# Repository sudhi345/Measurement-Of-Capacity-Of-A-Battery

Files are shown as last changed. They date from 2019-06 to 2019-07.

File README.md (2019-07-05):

# mAhTime

### Objective :

To calculate the battery life for a device using small batteries and intern use the data to calculate for any bigger battery.

###  Why do we need this?

The capacity of a battery is measured in Ah (ampere-hours, for large batteries) or mAh (milliampere-hours, for small batteries). 
This is usually mentioned on the battery or in the datasheets provided by the manufacturer.
But the capacity changes depending on the age of the battery, operating conditions, slightly different chemical composition, etc. 
So it affects the final result if use the capacity value provided by the manufacturer. 
*[learn more.](https://batteryuniversity.com/learn/article/battery_definitions)*
 
To get the actual capacity (close-enough-value), measuring the same is the method. 
Different methods using which one can measure the capacity, for example, Coulomb counting, Voltage monitoring, etc.
*(Learn more [here](https://www.quora.com/How-can-we-measure-a-batterys-real-capacity-in-Mah-or-ah-accurately) or 
[here](https://batteryuniversity.com/learn/article/how_to_measure_capacity)).*

Here we use the second method; monitoring the terminal voltage when a known load (resistive) is connected. 

### Method:

The batteries are charged and connected to a custom-designed shield for the esp8266 microcontroller and a load is selected using a button.
The microcontroller logs the terminal voltage read from its pin to a remote server until the lower cut off voltage for the batteries is reached.
The loads are automatically disconnected using logic level p-MOS switches. 
A python script displays the discharge curve and the area under the 
curve (area under the V*I v/s t curve is power rating and area under the I v/s t curve is the mAh / Ah of the batteries).<br>
Once again the batteries are charged but this time Device Under Test (DUT) is selected instead of a load (using the same microcontroller). 
The time taken for the DUT to discharge the batteries is found. This can then be used to calculate the life of any battery using ratios 
( Eg.: If for X (mAh) it is Y (no. of days) then for Z (mAh)? = YZ/X ).

### Hardware & Firmware:

A microcontroller unit (ESP8266-12E on LOLin board) has an inbuilt ADC (Analog to Digital Converter) with a precision of (1/1024)th of a volt.
But the input voltage range is only 0 (0) - 1V (1024). To use this in 0 - 3V range a resistor voltage divider is implemented 
using precision resistors and an n- MOS switch to enable this voltage divider.
The voltage divider is not the one which is present on the LOLin board. Those are not precision resistors, 
hence the readings may not be accurate.
The n-MOS switch is required as the voltage divider acts as another resistive load parallel to the selected load.
An OLED display is used to display the selected load, time, etc.

The hardware limits the maximum battery voltage to 3.6V as the battery voltage appears at pin A0 when voltage divider is disabled and the absolute maximum voltage given is 3.6V for esp8266. The time taken for measurement is determined by the capacity of the battery and the chosen load.

The circuit connections and the designed PCB can be found in the directory PCB_KICAD.
The details about the charger and the battery can be found in the 'Charger_hacked' directory. <br>
Arduino IDE is used to program the microcontroller. The required header files and libraries are in the 'upload_voltage' directory.

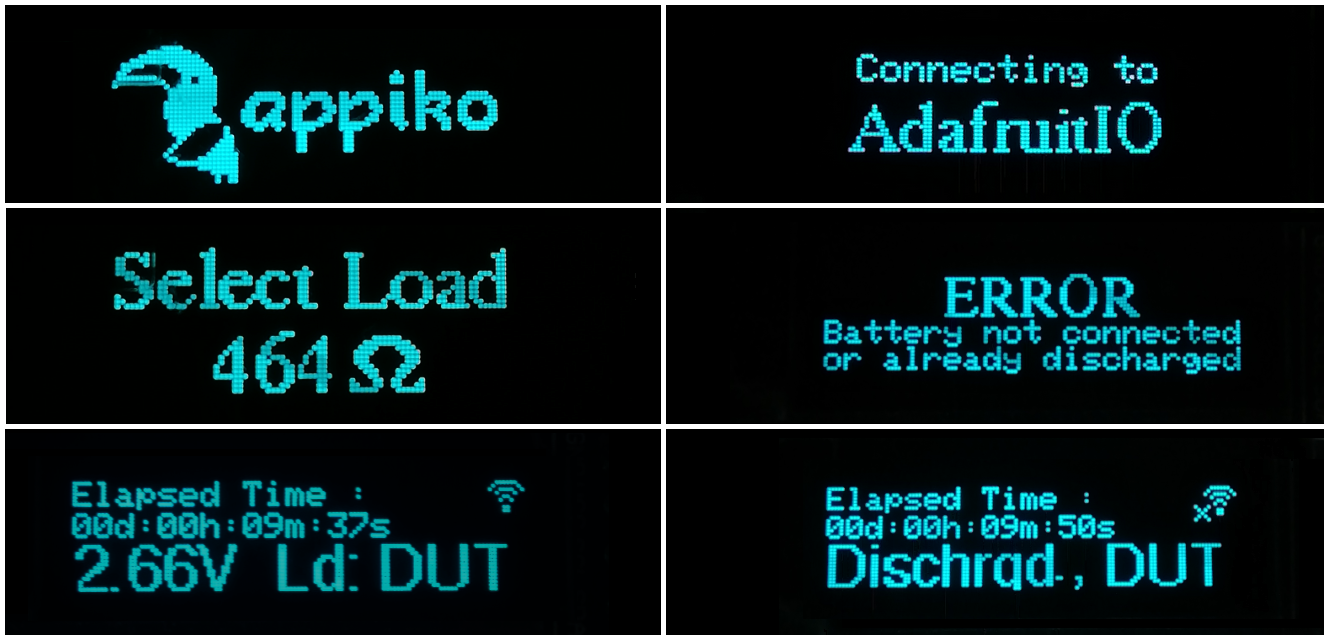
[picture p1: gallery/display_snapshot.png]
Snapshots of the display


### Result:

Here are pictures of graph and the PCB.
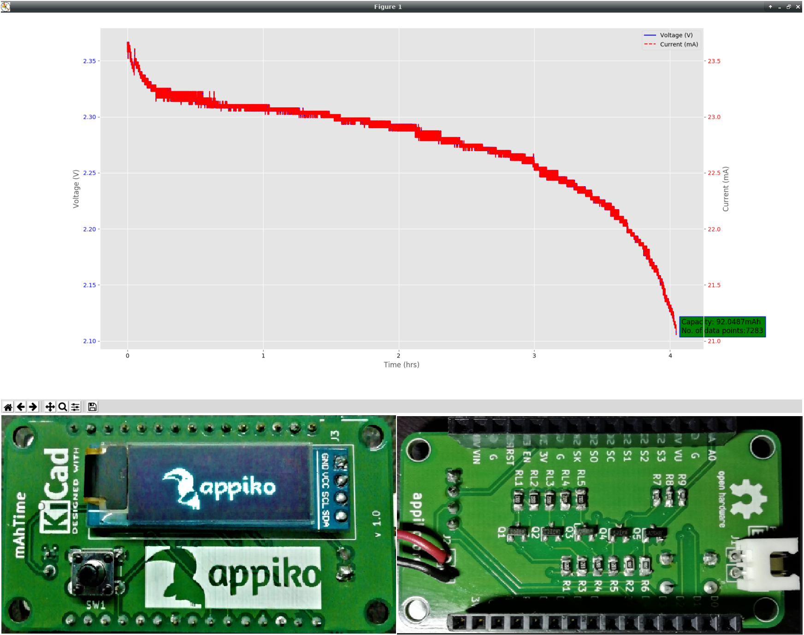
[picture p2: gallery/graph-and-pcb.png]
Graph and the soldered PCB


### Conclusion:

This project is helpful even if the DUT draws a few micro-amperes of current during sleep and few milli-amperes during high activity.
Hence the calculation of battery life is simplified with this.

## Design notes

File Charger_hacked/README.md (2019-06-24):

## Which battery and charger?

*Tuscan Gold* (model: TG-003) NiCd, NiMH battery charger to charge the *GP Battery* (17AAAH, 1.2V, C = 170mAh, NiMH,*1/3rd AAA*).

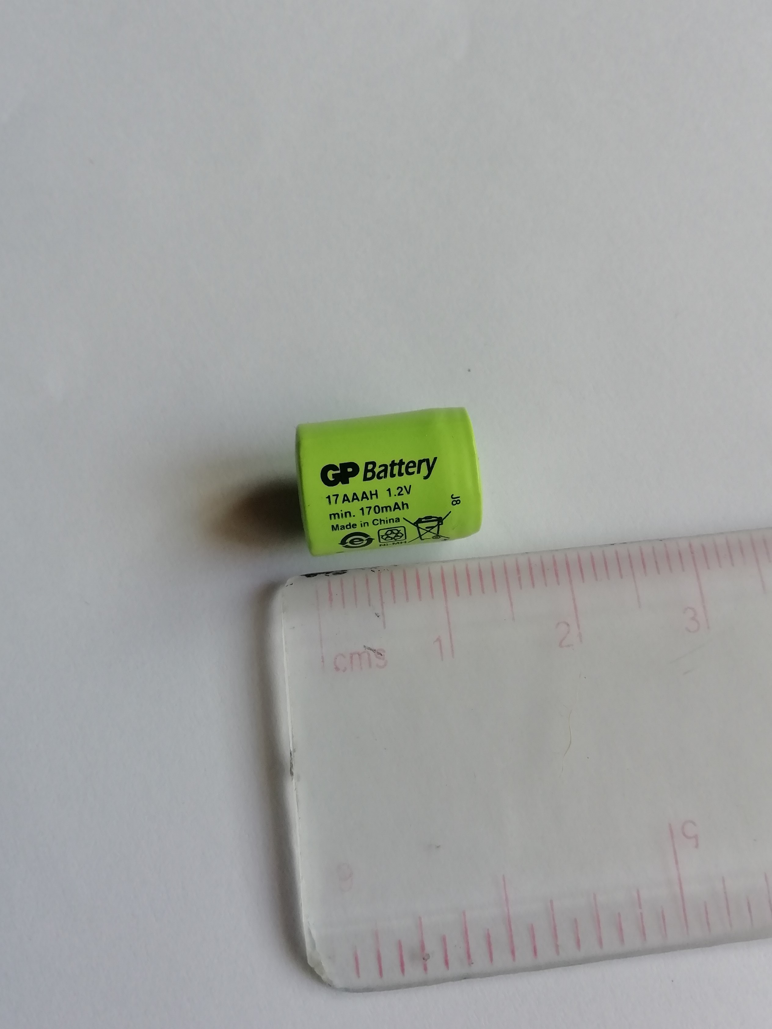
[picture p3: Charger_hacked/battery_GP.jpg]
1/3rd AAA battery


## Why the charger needs modifications?

Rated current capacity of the charger for the AAA size batteries (2S) is 100mA which is NOT the recommended amount of current for the 
mentioned tiny batteries. For the NiMH battery it is recommemnded to charge at 0.1C or below (usually 0.05C) but very low current through 
the batteries will result in a long charge duration.  Another problem with these tiny batteries is that they can not be installed in the given 
slot as that is for full sized AAA batteries.

## What are the modifications?

1. The over current problem was solved by adding a 147ohm resistor is series with the charger terminals and achieved a current flow of around 
12mA (~0.07C). Thses batteries (NiMH/NiCd) don't have floating terminal potential like Li-Ion batteries. So the change in voltage due to the 
added resistor across the terminals doesn't matter actually.
2. A pair of Molex connector was added to the charger with the wires connecting the terminals (One connector for 2S configuration. Resistor and
connections are invisible).

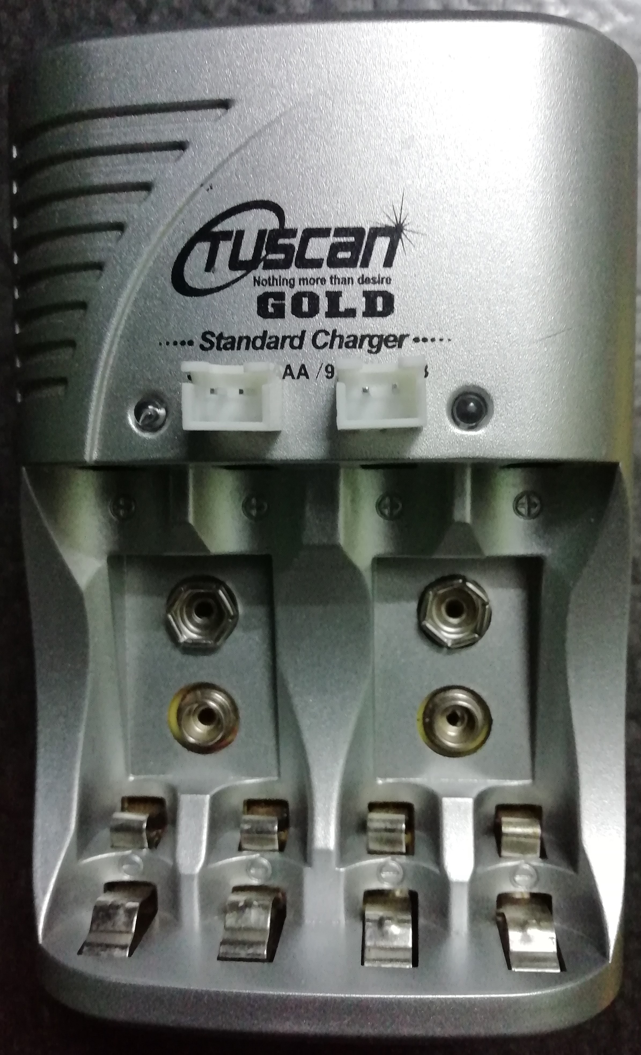
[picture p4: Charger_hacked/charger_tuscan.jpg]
Hacked charger


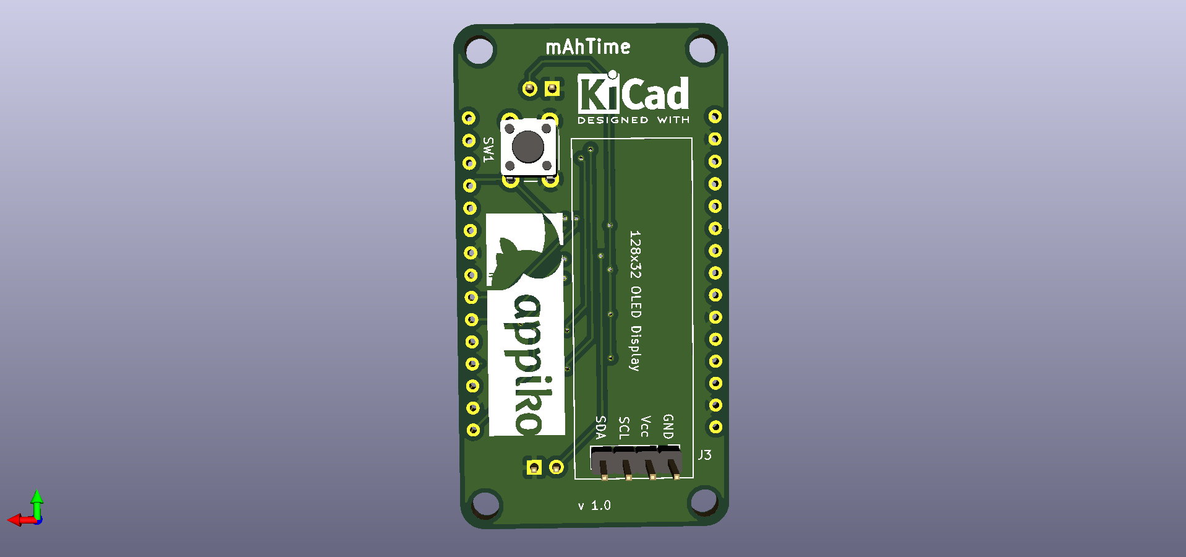
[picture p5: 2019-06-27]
PCB_KiCAD/images/pcb_3D_view_back.png

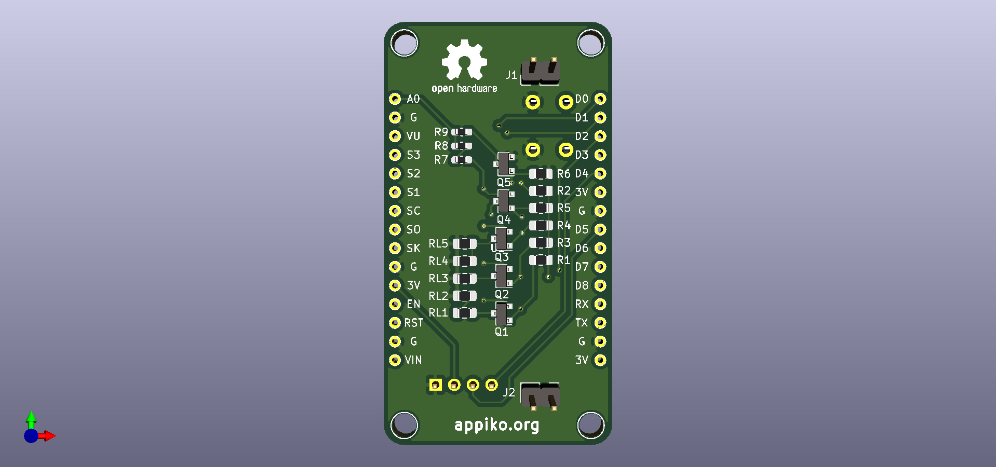
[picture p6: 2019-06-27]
PCB_KiCAD/images/pcb_3D_view.png

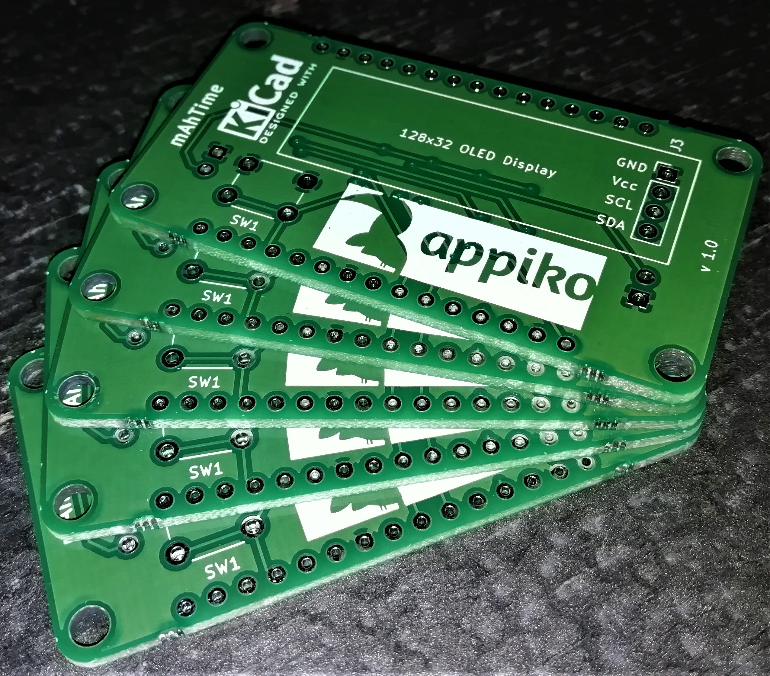
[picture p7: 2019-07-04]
gallery/pcb_stacked.jpg

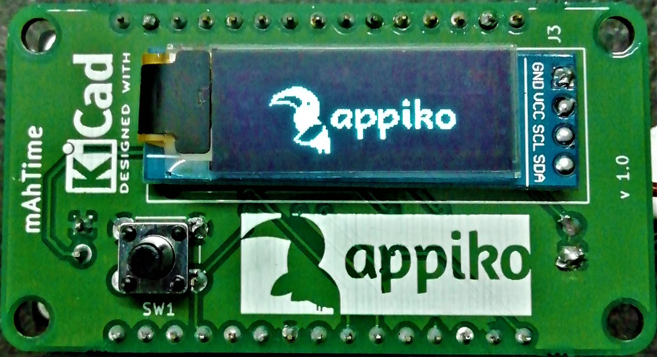
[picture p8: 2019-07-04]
gallery/pcb_powered.jpg

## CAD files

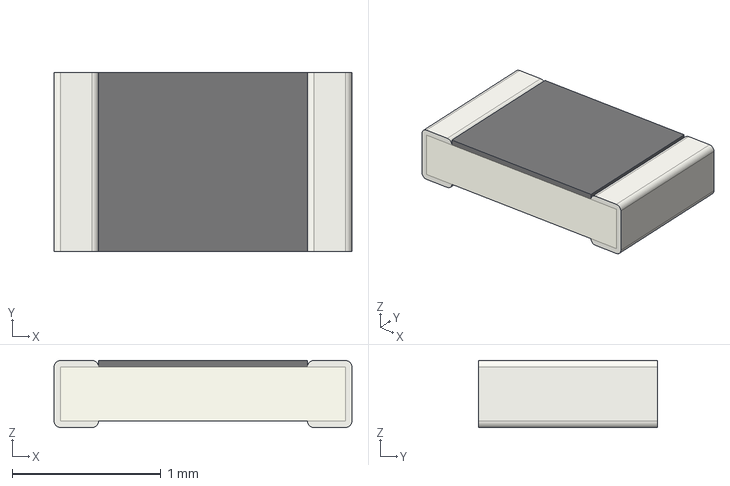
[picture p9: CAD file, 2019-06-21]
PCB_KiCAD/3D_models/R_0805_2012Metric.step
2.00 x 1.20 x 0.45 mm

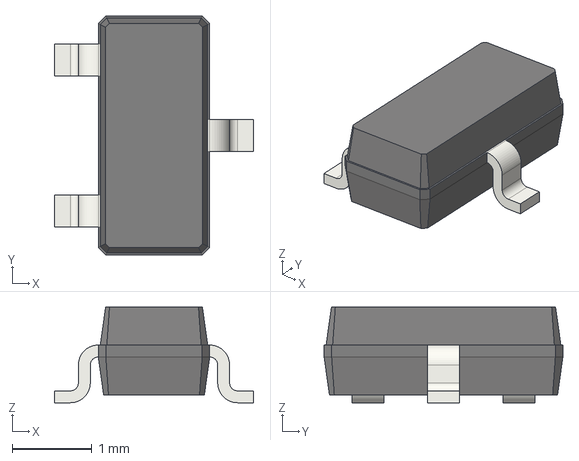
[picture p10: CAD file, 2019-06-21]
PCB_KiCAD/3D_models/SOT-23.step
2.50 x 3.00 x 1.20 mm

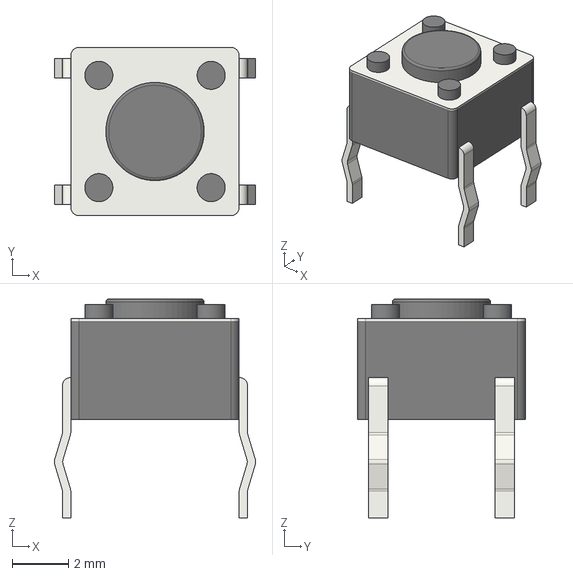
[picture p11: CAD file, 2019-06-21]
PCB_KiCAD/3D_models/SW_PUSH_6mm.step
7.17 x 6.00 x 7.80 mm

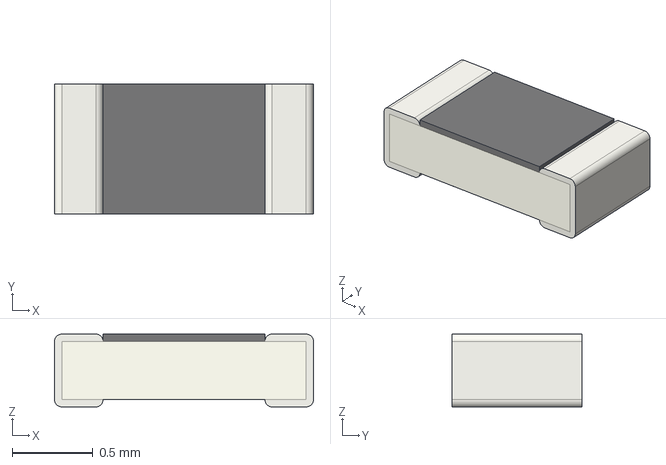
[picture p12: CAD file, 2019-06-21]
PCB_KiCAD/3D_models/R_0603_1608Metric.step
1.60 x 0.8 x 0.45 mm

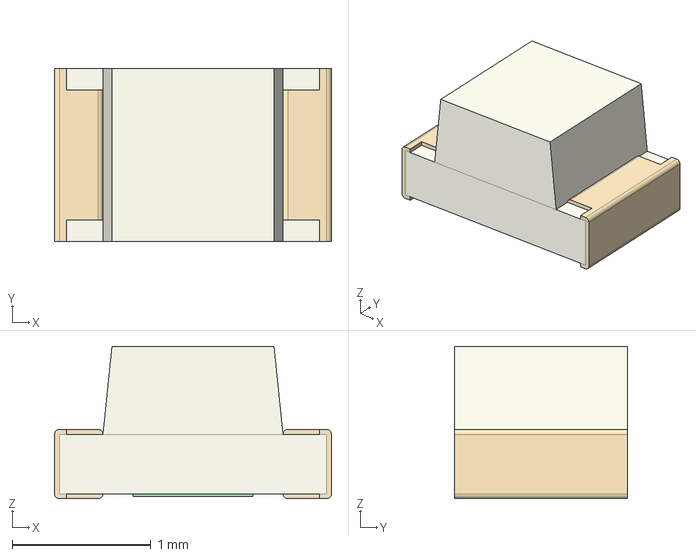
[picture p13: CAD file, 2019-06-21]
PCB_KiCAD/3D_models/LED_0805_2012Metric.step
2.00 x 1.25 x 1.10 mm

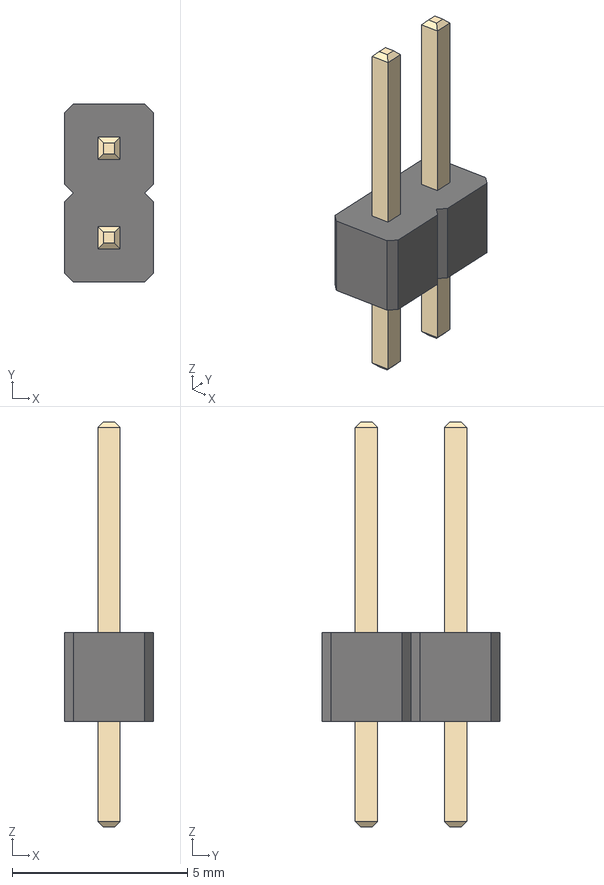
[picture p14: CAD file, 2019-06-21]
PCB_KiCAD/3D_models/PinHeader_1x02_P2.54mm_Vertical.step
2.54 x 5.08 x 11.5 mm

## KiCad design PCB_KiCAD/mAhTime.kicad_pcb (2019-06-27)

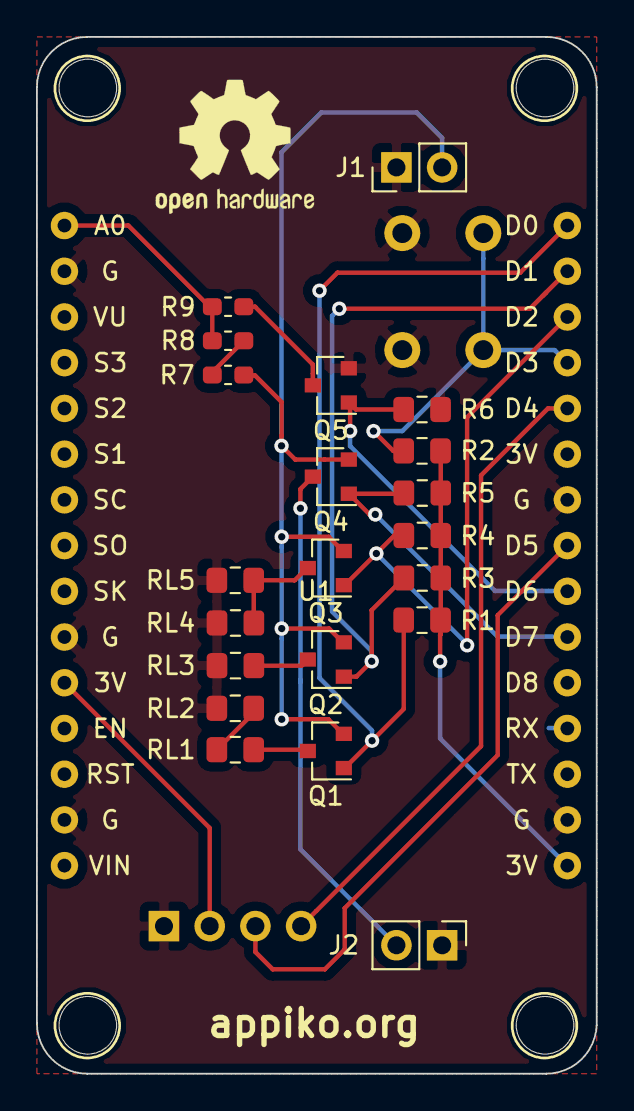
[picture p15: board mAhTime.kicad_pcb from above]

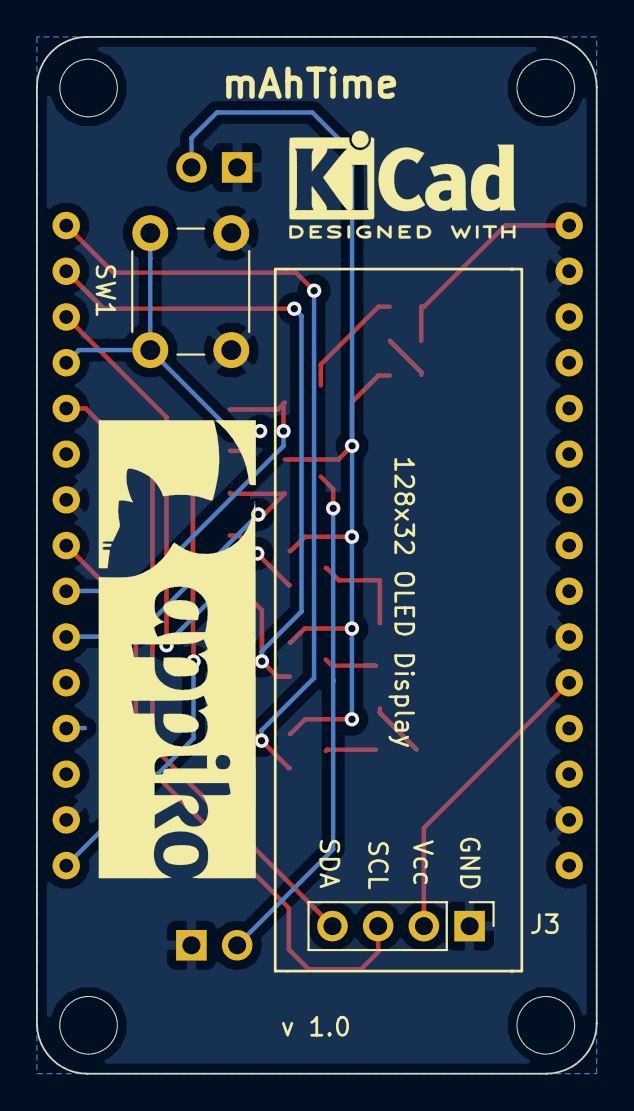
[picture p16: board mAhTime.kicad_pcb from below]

Board: 2 copper layers, 31.1 x 57.6 mm, 28 parts (2 on the bottom side), 19 nets.

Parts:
H1, H2, H3, H4: MountingHole; MountingHole_3.2mm_M3_ISO7380
J1: BATTERY; PinHeader_1x02_P2.54mm_Vertical
J2: DUT; PinHeader_1x02_P2.54mm_Vertical
J3: Conn_01x04; 128x32_OLED_Display
Q1, Q2, Q3, Q4: IRLML6401TRPBF; SOT-23
Q5: SI2302; SOT-23
R1, R3, R4, R5: 100k; R_0805_2012Metric_Pad1.15x1.40mm_HandSolder
R2: 1k; R_0805_2012Metric_Pad1.15x1.40mm_HandSolder
R6: 10k; R_0805_2012Metric_Pad1.15x1.40mm_HandSolder
R7, R8, R9: 30k; R_0603_1608Metric_Pad1.05x0.95mm_HandSolder
RL1, RL2, RL3, RL4, RL5: 232; R_0805_2012Metric_Pad1.15x1.40mm_HandSolder
SW1: SW_Push; SW_PUSH_6mm
U1: NodeMCU1.0(ESP-12E); NodeMCU-LoLinV3_without_border

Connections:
/Ctrl1: Q1.1, R1.2, U1.30
/Ctrl2: Q2.1, R3.2, U1.29
/Ctrl3: Q3.1, R4.2, U1.28
/Ctrl4: Q4.1, R5.2, U1.21
/En_VD: Q5.1, R6.2, U1.22
/SCL: J3.3, U1.23
/SDA: J3.4, U1.26
/SW: R2.2, SW1.1, U1.27
/Vbat: J1.2, Q1.2, Q2.2, Q3.2, Q4.2, R7.1
/Vcc: J3.2, R1.1, R2.1, R3.1, R4.1, R5.1, U1.11, U1.16, U1.25
/Vin: R8.2, R9.1, U1.1
/dut: J2.2, Q4.3
GND: J1.1, J2.1, J3.1, Q5.2, R6.1, RL2.2, RL3.2, RL4.2, RL5.2, SW1.2, U1.2, U1.10, U1.14, U1.17, U1.24
unnamed: Q1.3, RL1.1
unnamed: Q2.3, RL3.1
unnamed: Q3.3, RL4.1, RL5.1
unnamed: Q5.3, R9.2
unnamed: R7.2, R8.1
unnamed: RL1.2, RL2.1

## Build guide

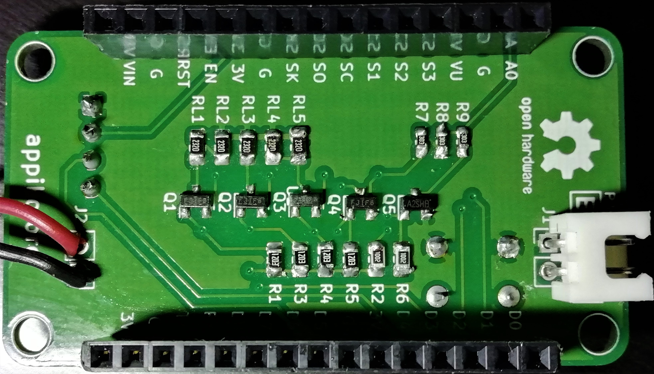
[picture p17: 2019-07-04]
gallery/pcb_soldered_2.jpg

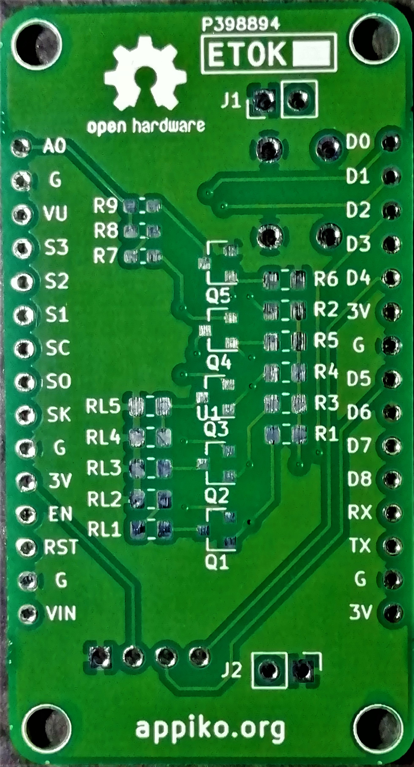
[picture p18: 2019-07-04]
gallery/pcb_unsoldered.jpg

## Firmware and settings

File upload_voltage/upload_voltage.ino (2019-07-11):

/********************************************************************************
BSD 3-Clause License

Copyright (c) 2019, Sudheendra Hegde
All rights reserved.

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
1. Redistributions of source code must retain the above copyright notice, this
   list of conditions and the following disclaimer.

2. Redistributions in binary form must reproduce the above copyright notice,
   this list of conditions and the following disclaimer in the documentation
   and/or other materials provided with the distribution.

3. Neither the name of the copyright holder nor the names of its
   contributors may be used to endorse or promote products derived from
   this software without specific prior written permission.

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
*****************************************************************************************/

#include "config.h"
#include "DischargeBattery.h"

float Vbat = 0, saved = 0;
float last = -1;

AdafruitIO_Feed *analog = io.feed("analog"); //Set up the feed. Replace "analog" in this line with the name of the feed that you created

void setup() {
  //set pinMode
  pinMode(LOAD1,OUTPUT);  //load resistance of 464ohm
  pinMode(LOAD2,OUTPUT);  //load resistance of 232ohm
  pinMode(LOAD3,OUTPUT);  //load resistance of 116ohm
  pinMode(DUT,OUTPUT);       //load is the Device Under Test (DUT)
  pinMode(SW,INPUT_PULLUP);         //push button (active high input)
  pinMode(EN_VOLTAGE_DIVIDER,OUTPUT);  //pin connected to gate of the mosfet which enables the voltage divider
  pinMode(Vin,INPUT);
  
  turnOffAllLoad();   //make sure all loads are off initially
  Wire.begin(SDA_PIN,SCL_PIN);
  display.begin(SSD1306_SWITCHCAPVCC, 0x3C);            // SSD1306_SWITCHCAPVCC = generate display voltage from 3.3V internally
  if(!display.begin(SSD1306_SWITCHCAPVCC, 0x3C)) {      // Address 0x3C for 128x32
    for(;;);                                            // SSD1306 allocation failed, Don't proceed, loop forever
  }
  display.clearDisplay();                       //clear the display buffer
  display.setRotation(2);                       //rotate 180 degerees
  display.drawBitmap(                           //draw bitmap image
    (display.width()  - logo_width ) / 2,       //align it at the center
    (display.height() - logo_height) / 2,
    logo, logo_width, logo_height, 1);
  display.display();                            //actually display the logo
  delay(2000);
  display.clearDisplay();        //clear the display buffer
  display.setTextSize(1);
  display.setTextColor(WHITE);
  display.setCursor(3,0);
  display.println("    Connecting to   ");
  display.setFont(&FreeSerif9pt7b);
  display.setCursor(0,24);
  display.println("     AdafruitIO    ");
  display.display(); // actually display all of the above
  
  io.connect();   // connect to io.adafruit.com
  
  // wait for a connection
  while(io.status() < AIO_CONNECTED) {
    delay(500);
  }
  display.clearDisplay();
  display.setCursor(25,18);
  display.println("Connected");
  display.display();
  delay(1000);
  queueInit();     //initialize queue
  checkBattery();   //verify whther connected battery has voltage > VLowerCutOff
  loadSelect();           //let the user select load / DUT
  display.setFont(&FreeSans9pt7b);  //change font to Sans
  StartTime = millis();     //save the starting time
}

void loop() {
  _time = millis();
  // io.run(); is required for all sketches. It should always be present at the top of your loop function. It keeps the client connected to
  // io.adafruit.com, and processes any incoming data.
  io.run();

  if( !ONCE_DISCHARGED )  
    Vbat = readVoltage();

  if( !(Vbat < VLowerCutOff) )
    enqueue(Vbat);    //enqueue the values 

  if(Vbat < VLowerCutOff)  {   //if the battery Vbat falls below the lower cut off
      ONCE_DISCHARGED = 1;         //clear the ONCE_DISCHARGED so that it does not oscillate when terminal Vbat rises slightly.
      turnOffAllLoad();    //turn OFF ALL loads when batteries got fully discharged.
      EndTime = millis();  //store end time
      DISP_ON = 1; //display that the batteries got discharged
      displayedAt = millis ();  //this is required when display is turned on using DISP_ON
      while(1){
        if (rear != front)    //queue is not empty
          if(!(io.status() < AIO_CONNECTED)) {     //connected 
            saved = dequeue();                             //read value from the queue
            analog->save(saved);                           // save the value to the feed
          } 
        checkForUpdate();
        yield();  
     }
  }
  
  while( (millis() - _time) < 2000){    //wait for 2 seconds
      checkForUpdate();
      if (rear != front)    //queue is not empty
        if(!(io.status() < AIO_CONNECTED)) {     //connected 
          saved = dequeue();                             //read value from the queue
          analog->save(saved);                           // save the value to the feed
        }
      yield();
  }
}

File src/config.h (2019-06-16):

/************************ Adafruit IO Config *******************************/

// visit io.adafruit.com if you need to create an account,
// or if you need your Adafruit IO key.
#define IO_USERNAME  "Username"
#define IO_KEY       "AIO"

/******************************* WIFI **************************************/

// the AdafruitIO_WiFi client will work with the following boards:
//   - HUZZAH ESP8266 Breakout -> https://www.adafruit.com/products/2471
//   - Feather HUZZAH ESP8266 -> https://www.adafruit.com/products/2821
//   - Feather HUZZAH ESP32 -> https://www.adafruit.com/product/3405
//   - Feather M0 WiFi -> https://www.adafruit.com/products/3010
//   - Feather WICED -> https://www.adafruit.com/products/3056
//   - Adafruit PyPortal -> https://www.adafruit.com/product/4116
//   - Adafruit Metro M4 Express AirLift Lite -> https://www.adafruit.com/product/4000
//   - Adafruit AirLift Breakout -> https://www.adafruit.com/product/4201

#define WIFI_SSID   "yourwifi"
#define WIFI_PASS   "wifipassword"

// uncomment the following line if you are using airlift
// #define USE_AIRLIFT

// uncomment the following line if you are using winc1500
// #define USE_WINC1500

// comment out the following lines if you are using fona or ethernet
#include "AdafruitIO_WiFi.h"

#if defined(USE_AIRLIFT) || defined(ADAFRUIT_METRO_M4_AIRLIFT_LITE)
  // Configure the pins used for the ESP32 connection
  #if !defined(SPIWIFI_SS) // if the wifi definition isnt in the board variant
    // Don't change the names of these #define's! they match the variant ones
    #define SPIWIFI SPI
    #define SPIWIFI_SS 10  // Chip select pin
    #define SPIWIFI_ACK 9  // a.k.a BUSY or READY pin
    #define ESP32_RESETN 6 // Reset pin
    #define ESP32_GPIO0 -1 // Not connected
  #endif
  AdafruitIO_WiFi io(IO_USERNAME, IO_KEY, WIFI_SSID, WIFI_PASS, SPIWIFI_SS, SPIWIFI_ACK, ESP32_RESETN, ESP32_GPIO0, &SPIWIFI);
#else
  AdafruitIO_WiFi io(IO_USERNAME, IO_KEY, WIFI_SSID, WIFI_PASS);
#endif
/******************************* FONA **************************************/

// the AdafruitIO_FONA client will work with the following boards:
//   - Feather 32u4 FONA -> https://www.adafruit.com/product/3027

// uncomment the following two lines for 32u4 FONA,
// and comment out the AdafruitIO_WiFi client in the WIFI section
// #include "AdafruitIO_FONA.h"
// AdafruitIO_FONA io(IO_USERNAME, IO_KEY);

/**************************** ETHERNET ************************************/

// the AdafruitIO_Ethernet client will work with the following boards:
//   - Ethernet FeatherWing -> https://www.adafruit.com/products/3201

// uncomment the following two lines for ethernet,
// and comment out the AdafruitIO_WiFi client in the WIFI section
// #include "AdafruitIO_Ethernet.h"
// AdafruitIO_Ethernet io(IO_USERNAME, IO_KEY);

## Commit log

2019-06-16 add code for esp8266 (Arduino IDE)
2019-06-16 added details about the charger
2019-06-16 changed pin number and defined const for lower cut off
2019-06-19 update schematic
    [CapacityOfBattery.sch]
2019-06-19 updated pcb
    [CapacityOfBattery.kicad_pcb, CapacityOfBattery.sch]
2019-06-20 modified PCB
    [CapacityOfBattery.kicad_pcb, CapacityOfBattery.sch]
2019-06-20 added gerber and pdf files
    [CapacityOfBattery-B.Adhes.gbr, CapacityOfBattery-B.CrtYd.gbr, CapacityOfBattery-B.Cu.gbr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]
2019-06-20 update pcb
    [CapacityOfBattery.kicad_pcb, CapacityOfBattery.sch]
2019-06-21 changed pcb layout
    [CapacityOfBattery.sch]
2019-06-21 pcb updated
    [CapacityOfBattery.kicad_pcb]
2019-06-21 created folder for pcb files
    [CapacityOfBattery.kicad_pcb, CapacityOfBattery.sch]
2019-06-21 updated BOM
    [CapacityOfBattery-B.Adhes.gbr, CapacityOfBattery-B.CrtYd.gbr, CapacityOfBattery-B.Cu.gbr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]
2019-06-21 changed folders and libraries
    [CapacityOfBattery-B.Adhes.gbr, CapacityOfBattery-B.CrtYd.gbr, CapacityOfBattery-B.Cu.gbr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]
2019-06-21 added 3d models
    [LED_0805_2012Metric.step, PinHeader_1x02_P2.54mm_Vertical.step, R_0603_1608Metric.step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]
2019-06-21 modified position of J2
    [CapacityOfBattery.kicad_pcb]
2019-06-21 updated images
    [CapacityOfBattery.kicad_pcb]
2019-06-23 changed code and schematic
    [CapacityOfBattery.sch]
2019-06-24 added dummy
    [testdata.csv]
2019-06-24 improved script
    [analog-1142.csv, analog-20190614-1142.csv, testdata.csv]
2019-06-24 updated gerber and pdf
    [CapacityOfBattery-B.Adhes.gbr, CapacityOfBattery-B.CrtYd.gbr, CapacityOfBattery-B.Cu.gbr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]
2019-06-25 updated code
    [CapacityOfBattery-B.Adhes.gbr, CapacityOfBattery-B.CrtYd.gbr, CapacityOfBattery-B.Cu.gbr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]
2019-06-27 Updated images and files
    [mAhTime-B.Adhes.gbr, mAhTime-B.CrtYd.gbr, mAhTime-B.Cu.gbr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]
2019-06-29 Modified code
    [analog.csv]
2019-07-04 Upload images
    [analogtest3.csv]
2019-07-04 Updated files
    [analog093.csv, analog100.csv, analog116.csv]

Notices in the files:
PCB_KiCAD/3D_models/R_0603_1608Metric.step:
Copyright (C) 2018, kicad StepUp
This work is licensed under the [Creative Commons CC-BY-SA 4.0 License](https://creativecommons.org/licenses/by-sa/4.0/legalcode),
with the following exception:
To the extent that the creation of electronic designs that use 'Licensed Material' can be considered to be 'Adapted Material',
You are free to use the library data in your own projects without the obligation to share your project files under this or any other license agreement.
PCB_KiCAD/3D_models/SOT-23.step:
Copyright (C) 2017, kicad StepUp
